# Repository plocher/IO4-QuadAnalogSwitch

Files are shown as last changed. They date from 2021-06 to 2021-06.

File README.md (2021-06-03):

# IO4-QuadAnalogSwitch
## License: CERN Open Hardware Licence v1.2

Quad Analog switch - 16 inputs to 4 A/D lines

An ESP32 only has 4x usable A/D lines when WiFi is also used.
This board is a multiplexor for 4 banks of 4 analog inputs to those A/D lines.

The initial use case is to support a preset controller for LED layout lighting
that has R,G,B and W levels for Background horizon, background sky, foreground sky and suplementary lighting.
(that is, 4 banks of 4 linear potentiometers each...)

Usage:

Set the digital outputs to select the desired bank:

    D C B A  
    X 0 1 1	Bank A  
    X 0 0 1	Bank B  
    X 1 0 0	Bank C  
    X 0 0 0	Bank D    

(output "D" controls a diagnostic LED on the board)

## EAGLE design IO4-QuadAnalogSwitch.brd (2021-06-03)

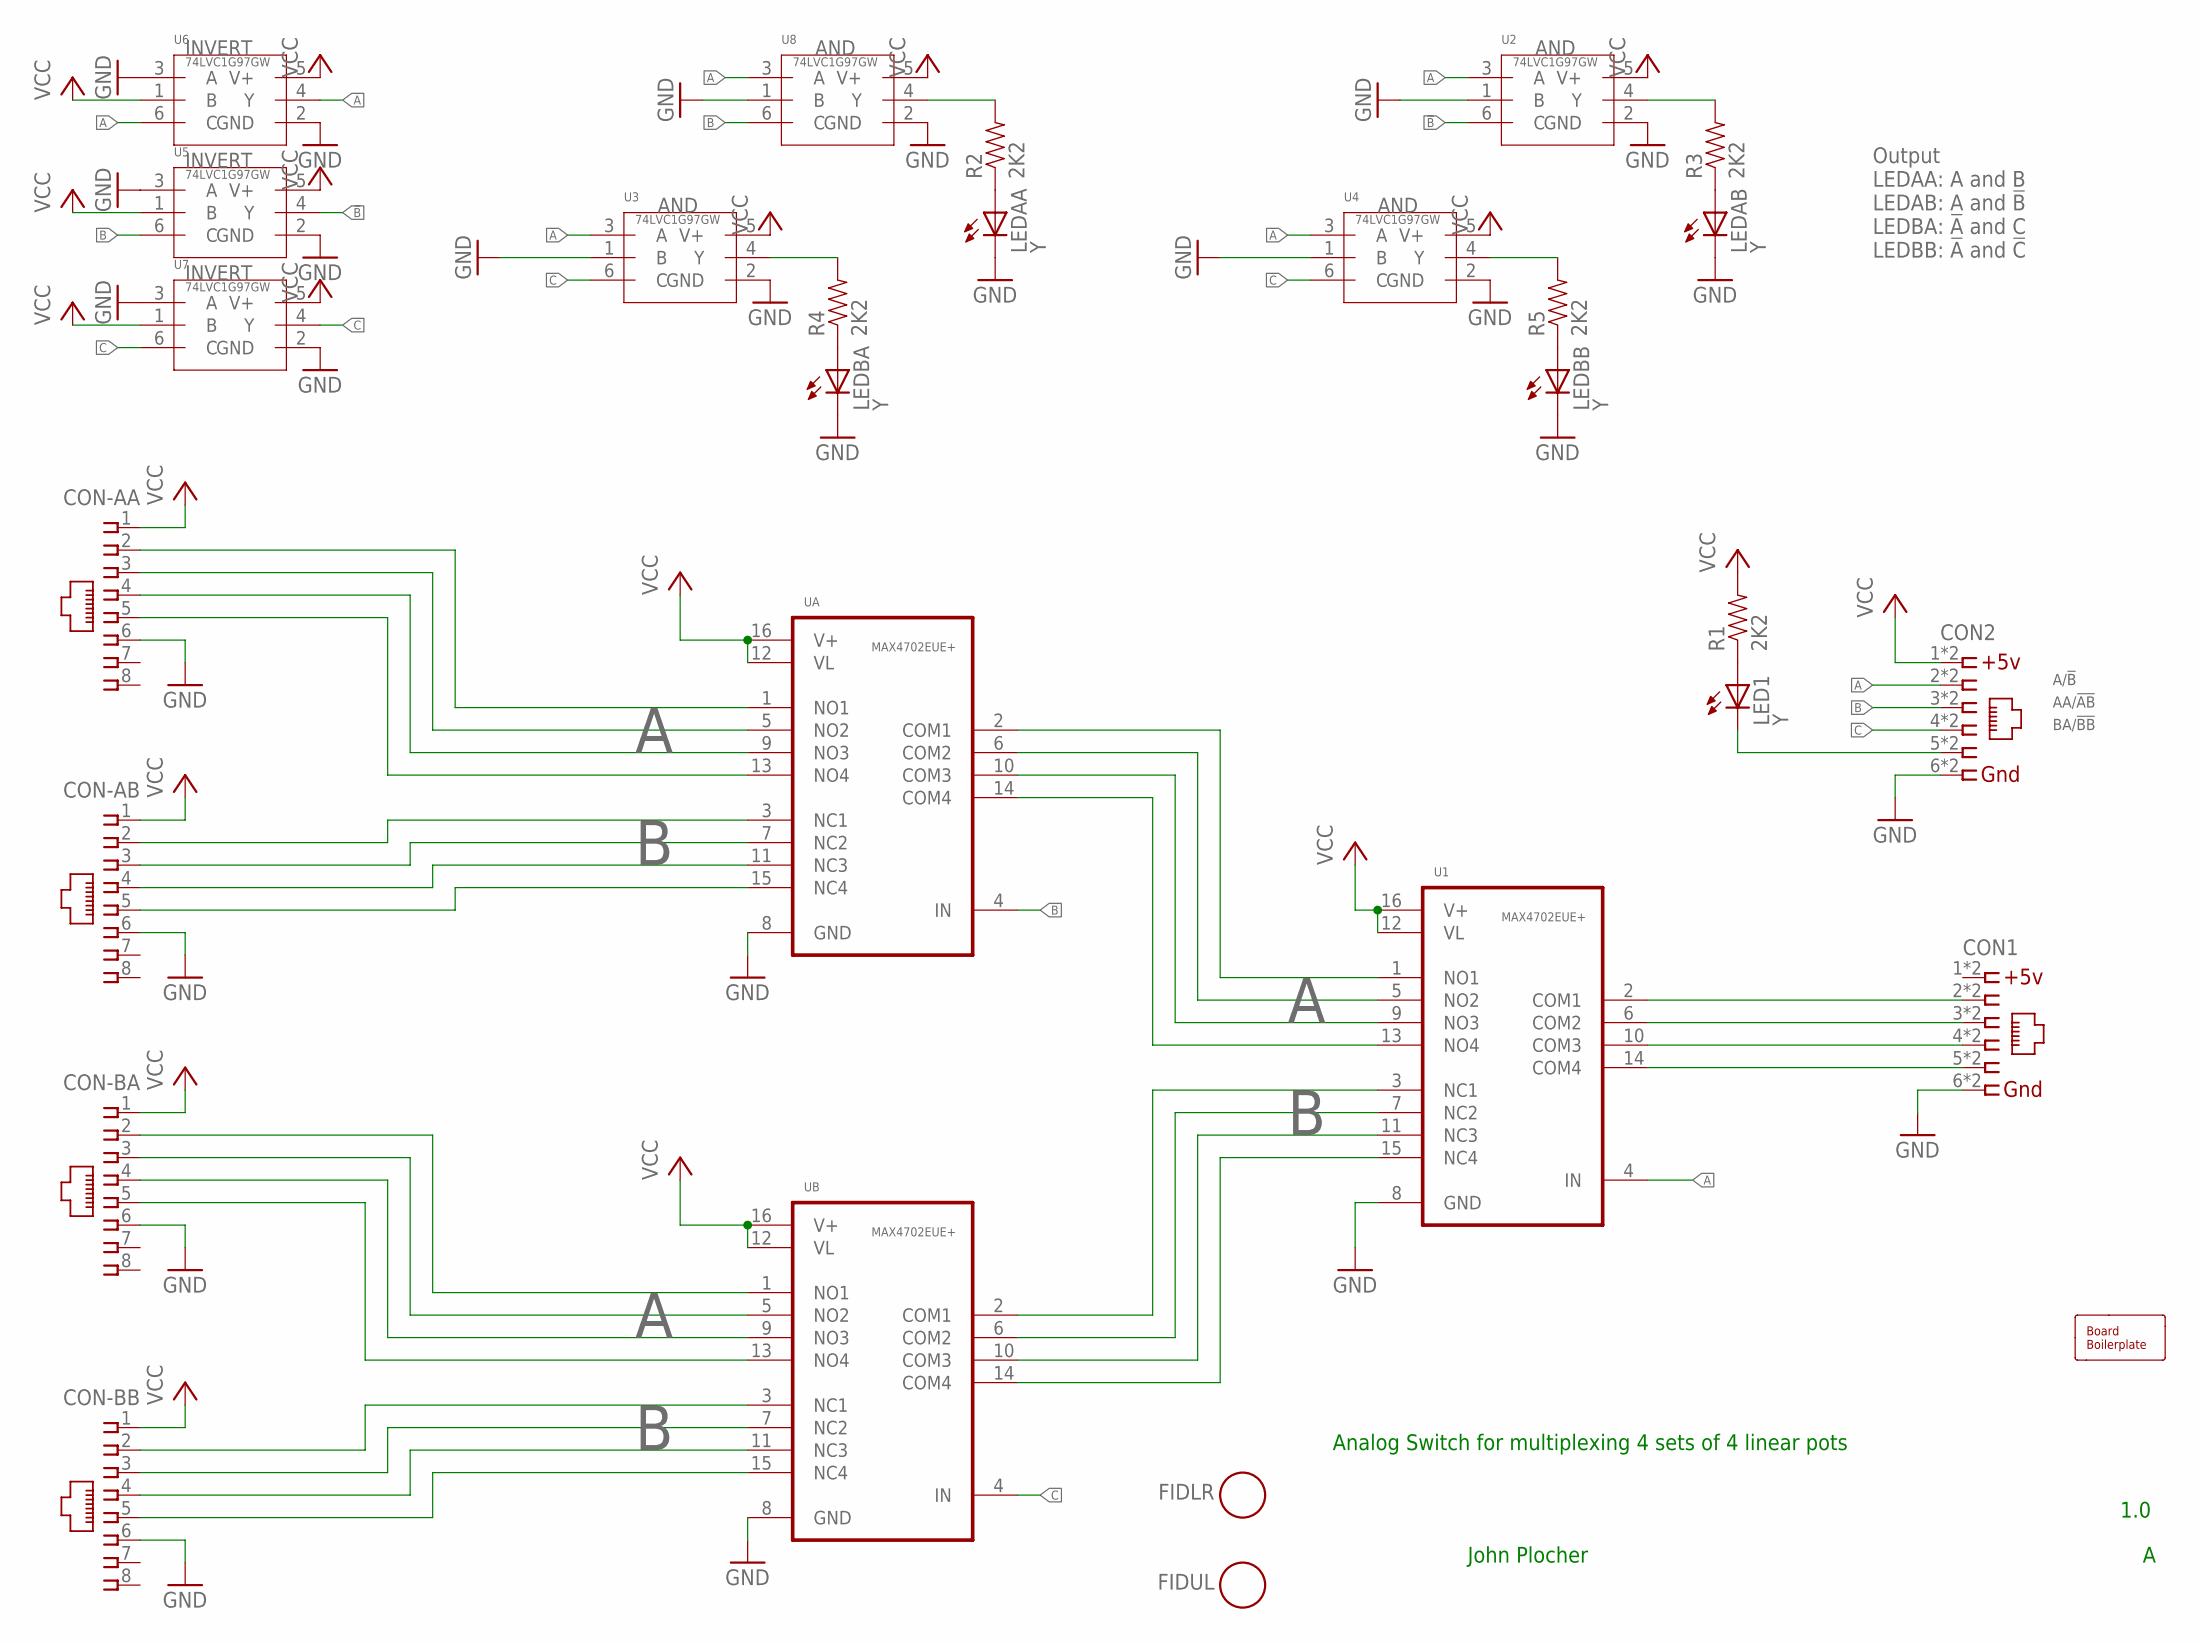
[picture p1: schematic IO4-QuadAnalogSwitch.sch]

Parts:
BOARD1: BOARD80X100; BOARD-DINRAIL-3.17INX10CM
CON1, CON2: CONNECTOR-IO4IPINS; RJ24-INVERTED-PINS
CON-AA: CONNECTOR-RJ45-FRONT; RJ45-NO-SHIELD
CON-AB: CONNECTOR-RJ45-FRONT; RJ45-NO-SHIELD
CON-BA: CONNECTOR-RJ45-FRONT; RJ45-NO-SHIELD
CON-BB: CONNECTOR-RJ45-FRONT; RJ45-NO-SHIELD
FIDLR: FIDUCIAL; FIDUCIAL_1MM
FIDUL: FIDUCIAL; FIDUCIAL_1MM
LED1: Y; 0603-LED
LEDAA: Y; 0603-LED
LEDAB: Y; 0603-LED
LEDBA: Y; 0603-LED
LEDBB: Y; 0603-LED
R1, R2, R3, R4, R5: 2K2; 0603-RES
U1: MAX4702EUE+
U2, U3, U4, U5, U6, U7, U8: 74LVC1G97GW; SOT363
UA: MAX4702EUE+
UB: MAX4702EUE+

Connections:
1: CON1.1, CON1.1@1 (1)
!A: U3.3 (A), U4.3 (A), U6.4 (Y)
!B: U2.6 (C), U5.4 (Y)
!C: U4.6 (C), U7.4 (Y)
A: CON2.2, CON2.2@1 (2), U1.4 (IN), U2.3 (A), U6.6 (C), U8.3 (A)
A1: U1.1 (NO1), UA.2 (COM1)
A2: U1.5 (NO2), UA.6 (COM2)
A3: U1.9 (NO3), UA.10 (COM3)
A4: U1.13 (NO4), UA.14 (COM4)
AA1: CON-AA.2, UA.1 (NO1)
AA2: CON-AA.3, UA.5 (NO2)
AA3: CON-AA.4, UA.9 (NO3)
AA4: CON-AA.5, UA.13 (NO4)
AB1: CON-AB.2, UA.3 (NC1)
AB2: CON-AB.3, UA.7 (NC2)
AB3: CON-AB.4, UA.11 (NC3)
AB4: CON-AB.5, UA.15 (NC4)
B: CON2.3, CON2.3@1 (3), U5.6 (C), U8.6 (C), UA.4 (IN)
B1: U1.3 (NC1), UB.2 (COM1)
B2: U1.7 (NC2), UB.6 (COM2)
B3: U1.11 (NC3), UB.10 (COM3)
B4: U1.15 (NC4), UB.14 (COM4)
BA1: CON-BA.2, UB.1 (NO1)
BA2: CON-BA.3, UB.5 (NO2)
BA3: CON-BA.4, UB.9 (NO3)
BA4: CON-BA.5, UB.13 (NO4)
BB1: CON-BB.2, UB.3 (NC1)
BB2: CON-BB.3, UB.7 (NC2)
BB3: CON-BB.4, UB.11 (NC3)
BB4: CON-BB.5, UB.15 (NC4)
C: CON2.4, CON2.4@1 (4), U3.6 (C), U7.6 (C), UB.4 (IN)
COM1: CON1.2, CON1.2@1 (2), U1.2 (COM1)
COM2: CON1.3, CON1.3@1 (3), U1.6 (COM2)
COM3: CON1.4, CON1.4@1 (4), U1.10 (COM3)
COM4: CON1.5, CON1.5@1 (5), U1.14 (COM4)
GND: CON1.6, CON1.6@1 (6), CON2.6, CON2.6@1 (6), CON-AA.6, CON-AB.6, CON-BA.6, CON-BB.6, LEDAA.C, LEDAB.C, LEDBA.C, LEDBB.C, U1.8 (GND), U2.1 (B), U2.2 (GND), U3.1 (B), U3.2 (GND), U4.1 (B), U4.2 (GND), U5.2 (GND), U5.3 (A), U6.2 (GND), U6.3 (A), U7.2 (GND), U7.3 (A), U8.1 (B), U8.2 (GND), UA.8 (GND), UB.8 (GND)
unnamed: LED1.A, R1.1
unnamed: CON2.5, CON2.5@1 (5), LED1.C
unnamed: LEDAA.A, R2.1
unnamed: LEDBB.A, R5.1
unnamed: LEDAB.A, R3.1
unnamed: R2.2, U8.4 (Y)
unnamed: LEDBA.A, R4.1
unnamed: R5.2, U4.4 (Y)
unnamed: R4.2, U3.4 (Y)
unnamed: R3.2, U2.4 (Y)
VCC: CON2.1, CON2.1@1 (1), CON-AA.1, CON-AB.1, CON-BA.1, CON-BB.1, R1.2, U1.12 (VL), U1.16 (V+), U2.5 (V+), U3.5 (V+), U4.5 (V+), U5.1 (B), U5.5 (V+), U6.1 (B), U6.5 (V+), U7.1 (B), U7.5 (V+), U8.5 (V+), UA.12 (VL), UA.16 (V+), UB.12 (VL), UB.16 (V+)

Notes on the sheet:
Analog Switch for multiplexing 4 sets of 4 linear pots
1.0
John Plocher
AND
INVERT
A/!B
AA/!AB
BA/!BB
Output LEDAA: A and B LEDAB: A and !B! LEDBA: !A! and C LEDBB: !A! and !C!

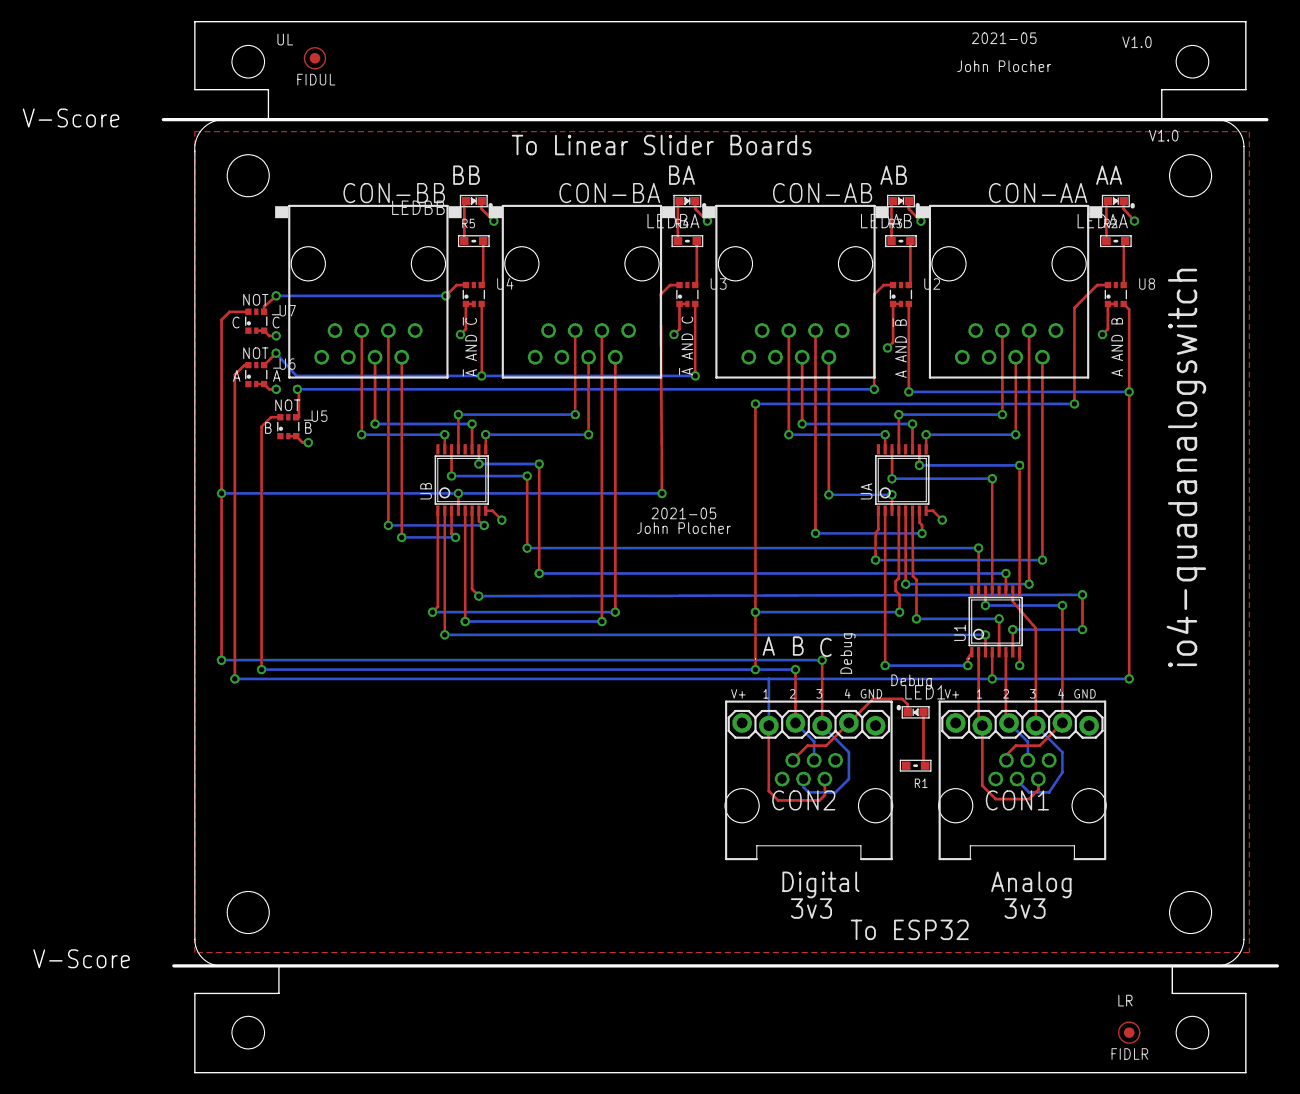
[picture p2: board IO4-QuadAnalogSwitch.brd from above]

Board: 2 copper layers, 106.0 x 100.0 mm, 29 parts (0 on the bottom side), 47 nets.

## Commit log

2021-06-03 Initial version
    [IO4-QuadAnalogSwitch copy.brd, IO4-QuadAnalogSwitch-fake.brd, IO4-QuadAnalogSwitch.brd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]
2021-06-03 missed tiny airwire
    [IO4-QuadAnalogSwitch.brd]
